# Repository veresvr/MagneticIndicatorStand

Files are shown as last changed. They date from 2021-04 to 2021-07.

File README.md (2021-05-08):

# Magnetic Indicator Stand

Designed for my small needs. You can make your own! All files are for SolidWorks 2020. Drawings are also available in .pdf

Assembly video is available on [YouTube](https://youtu.be/R4zijvSld24).  

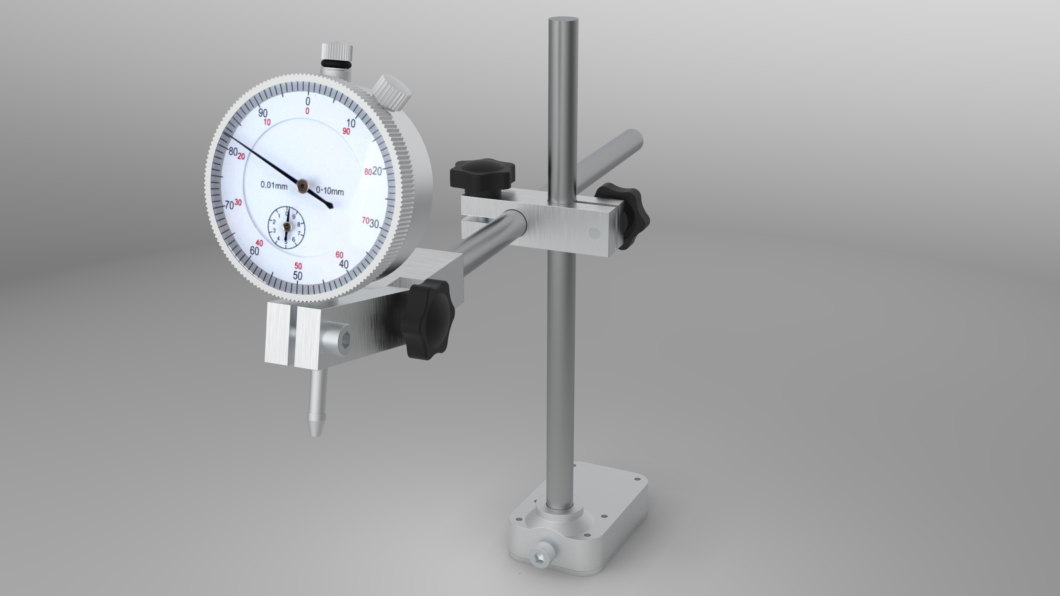
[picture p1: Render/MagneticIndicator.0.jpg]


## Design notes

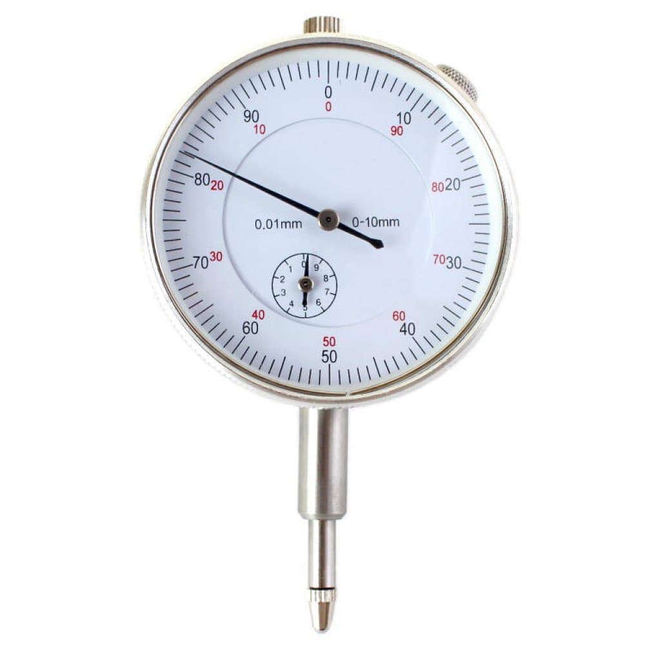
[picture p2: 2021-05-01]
Render/MagneticIndicator/photo_indicator.jpg

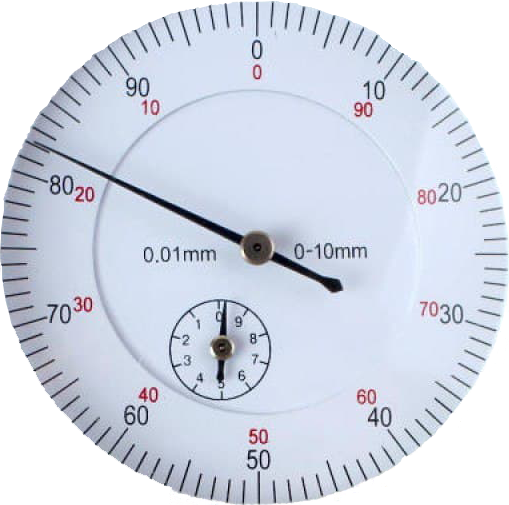
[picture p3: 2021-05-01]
Render/MagneticIndicator/photo_indicator.png

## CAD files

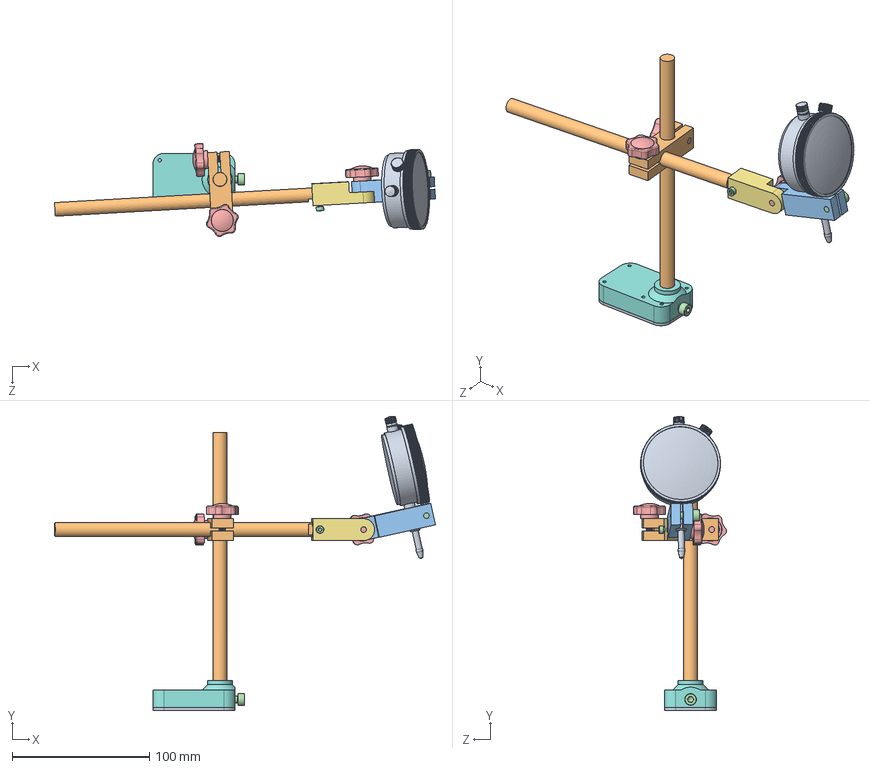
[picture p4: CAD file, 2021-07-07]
3D/MagneticIndicatorStand.SLDASM
277.9 x 214.5 x 68.0 mm
Dial Indicator
SteelRod x 2
IndicatorHolder
socket head cap screw_iso x 3
ClampingScrewKnob x 3
socket countersunk head screw_iso x 6
SecondPartOfIndicatorJoint
BasePart
Lid
MainJoint
Neodymium Magnet Square

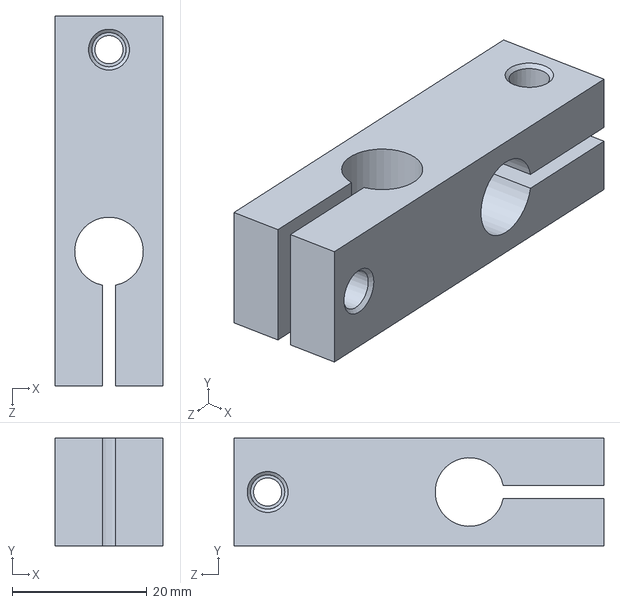
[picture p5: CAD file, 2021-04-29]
Render/AssemblyFiles/MainJoint.SLDPRT
16.0 x 16.0 x 55.0 mm

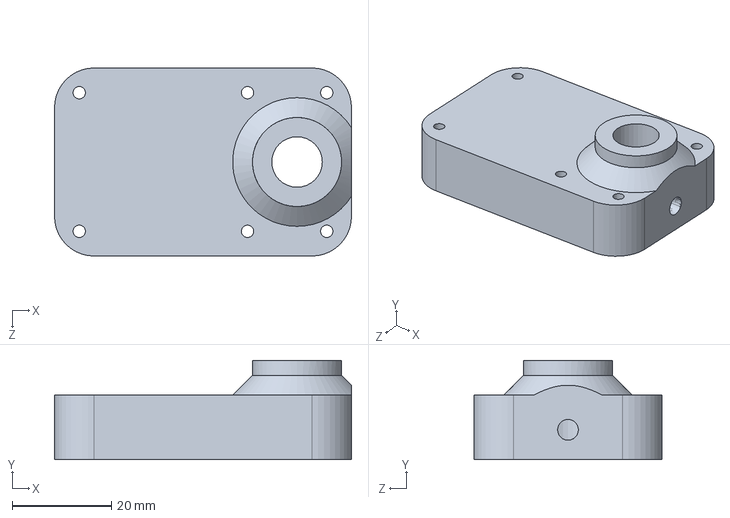
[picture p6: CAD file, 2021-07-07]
3D/BasePart.SLDPRT
60.0 x 20.0 x 38.0 mm

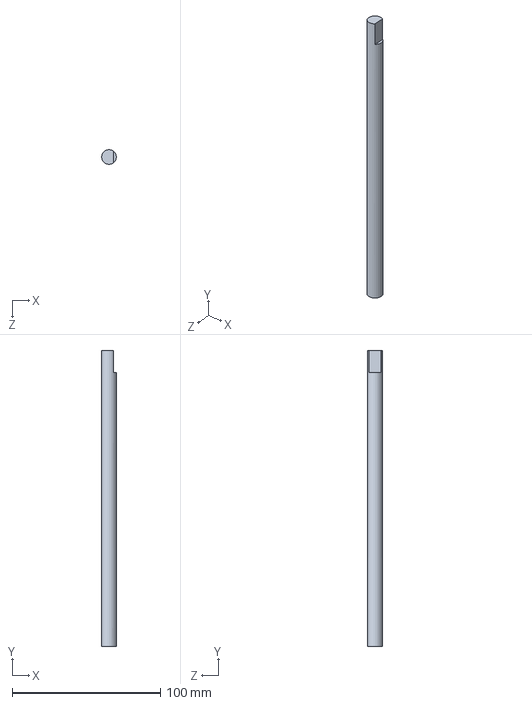
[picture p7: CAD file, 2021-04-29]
Render/AssemblyFiles/SteelRod.SLDPRT
10.0 x 200.0 x 10.0 mm

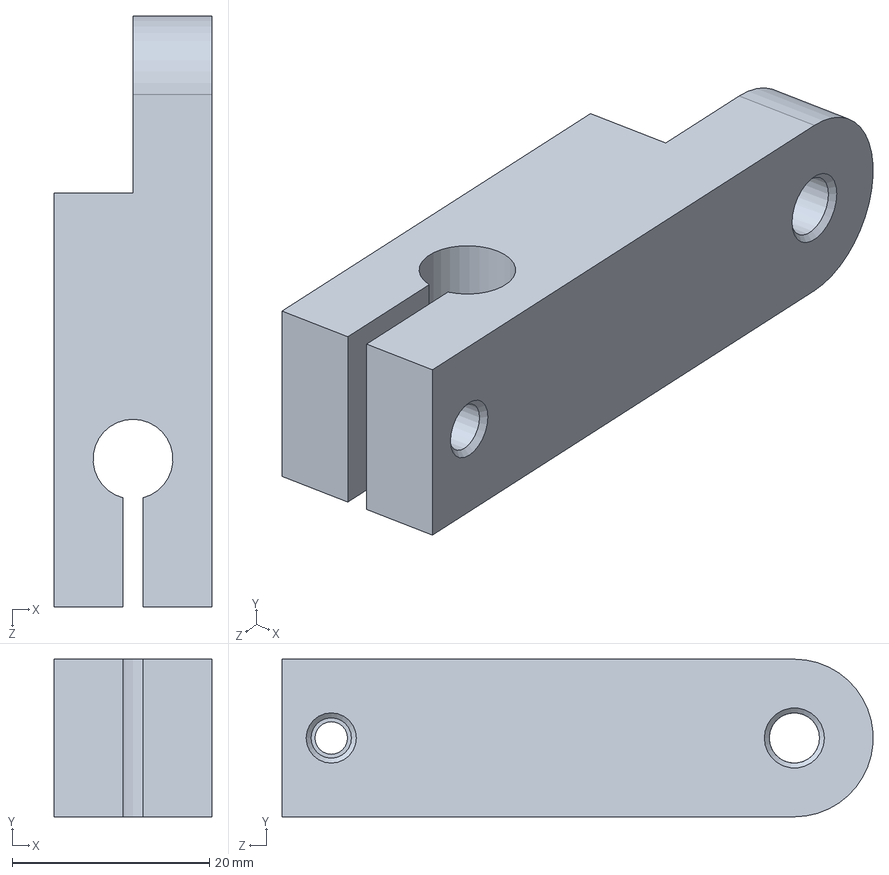
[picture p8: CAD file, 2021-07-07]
3D/IndicatorHolder.SLDPRT
16.0 x 16.0 x 60.0 mm

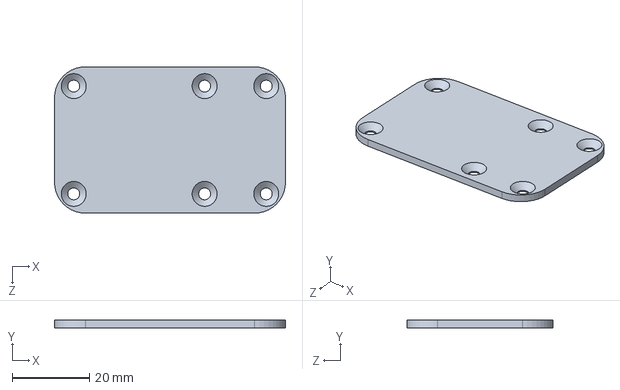
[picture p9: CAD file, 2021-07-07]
3D/Lid.SLDPRT
60.0 x 2.00 x 38.0 mm

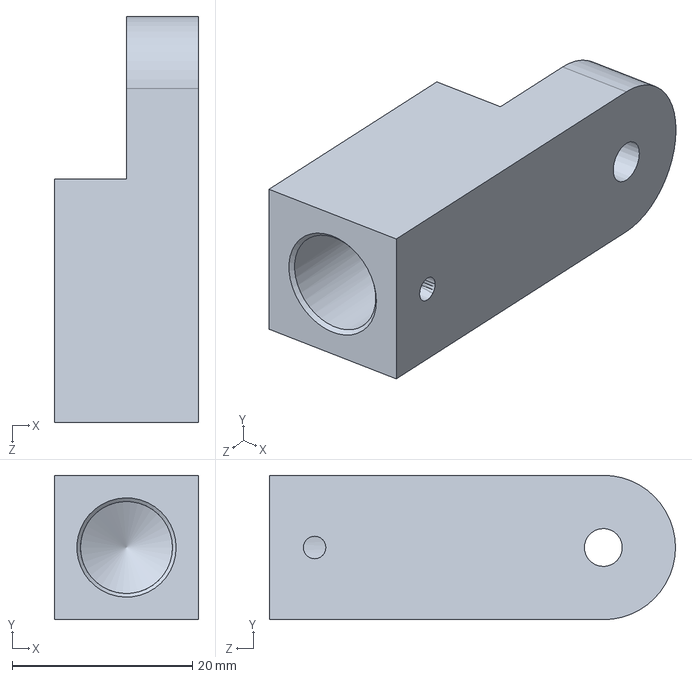
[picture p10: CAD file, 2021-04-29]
Render/AssemblyFiles/SecondPartOfIndicatorJoint.SLDPRT
16.0 x 16.0 x 45.0 mm

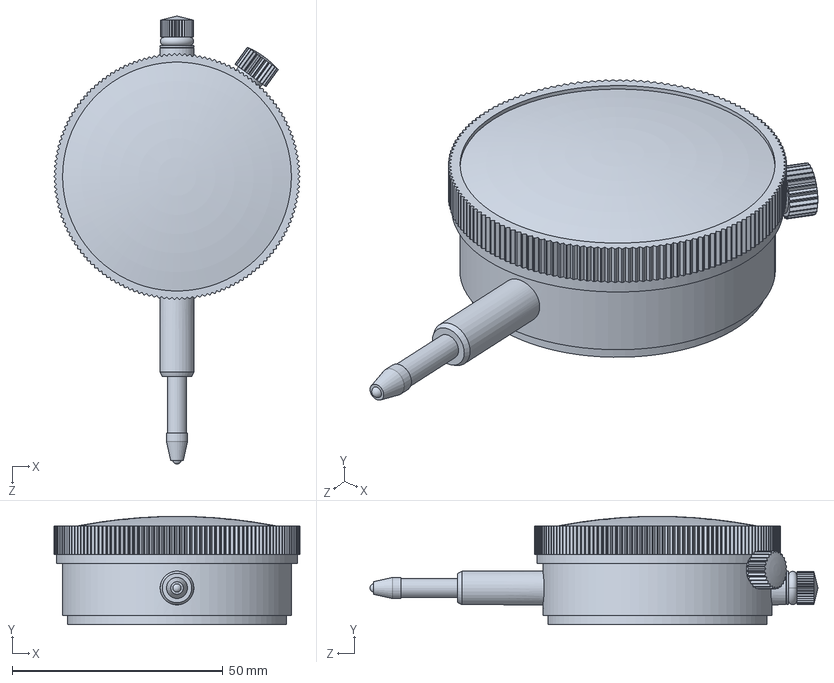
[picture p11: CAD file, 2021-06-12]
3D/Dial Indicator.SLDPRT
58.3 x 25.7 x 106.3 mm

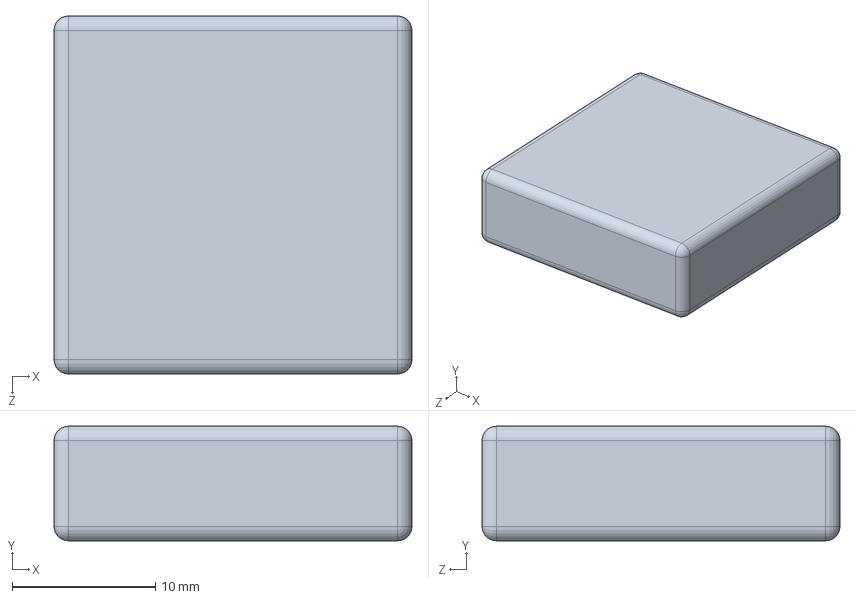
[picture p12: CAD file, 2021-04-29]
Render/AssemblyFiles/Neodymium Magnet Square.SLDPRT
25.0 x 8.00 x 25.0 mm

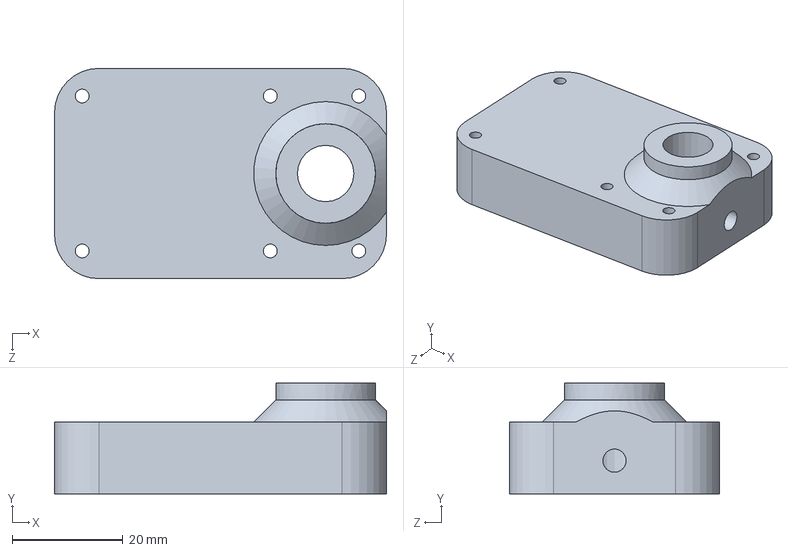
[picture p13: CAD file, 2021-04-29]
Render/AssemblyFiles/BasePart.SLDPRT
60.0 x 20.0 x 38.0 mm

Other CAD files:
3D/MainJoint.SLDPRT
Render/AssemblyFiles/MagneticIndicatorStand.SLDASM
3D/SecondPartOfIndicatorJoint.SLDPRT
Render/AssemblyFiles/IndicatorHolder.SLDPRT
3D/SteelRod.SLDPRT
3D/Neodymium Magnet Square.SLDPRT
Render/AssemblyFiles/Lid.SLDPRT
Render/AssemblyFiles/Dial Indicator.SLDPRT
3D/ClampingScrewKnob.SLDPRT
Drawings/BasePart.SLDDRW
Drawings/IndicatorHolder.SLDDRW
Drawings/Lid.SLDDRW
Drawings/MagneticIndicatorStand.SLDDRW
Drawings/MainJoint.SLDDRW
Drawings/SecondPartOfIndicatorJoint.SLDDRW
Drawings/SteelRod.SLDDRW
Render/AssemblyFiles/ClampingScrewKnob.SLDPRT
Render/AssemblyFiles/socket countersunk head screw_iso.sldprt
Render/AssemblyFiles/socket head cap screw_iso.sldprt

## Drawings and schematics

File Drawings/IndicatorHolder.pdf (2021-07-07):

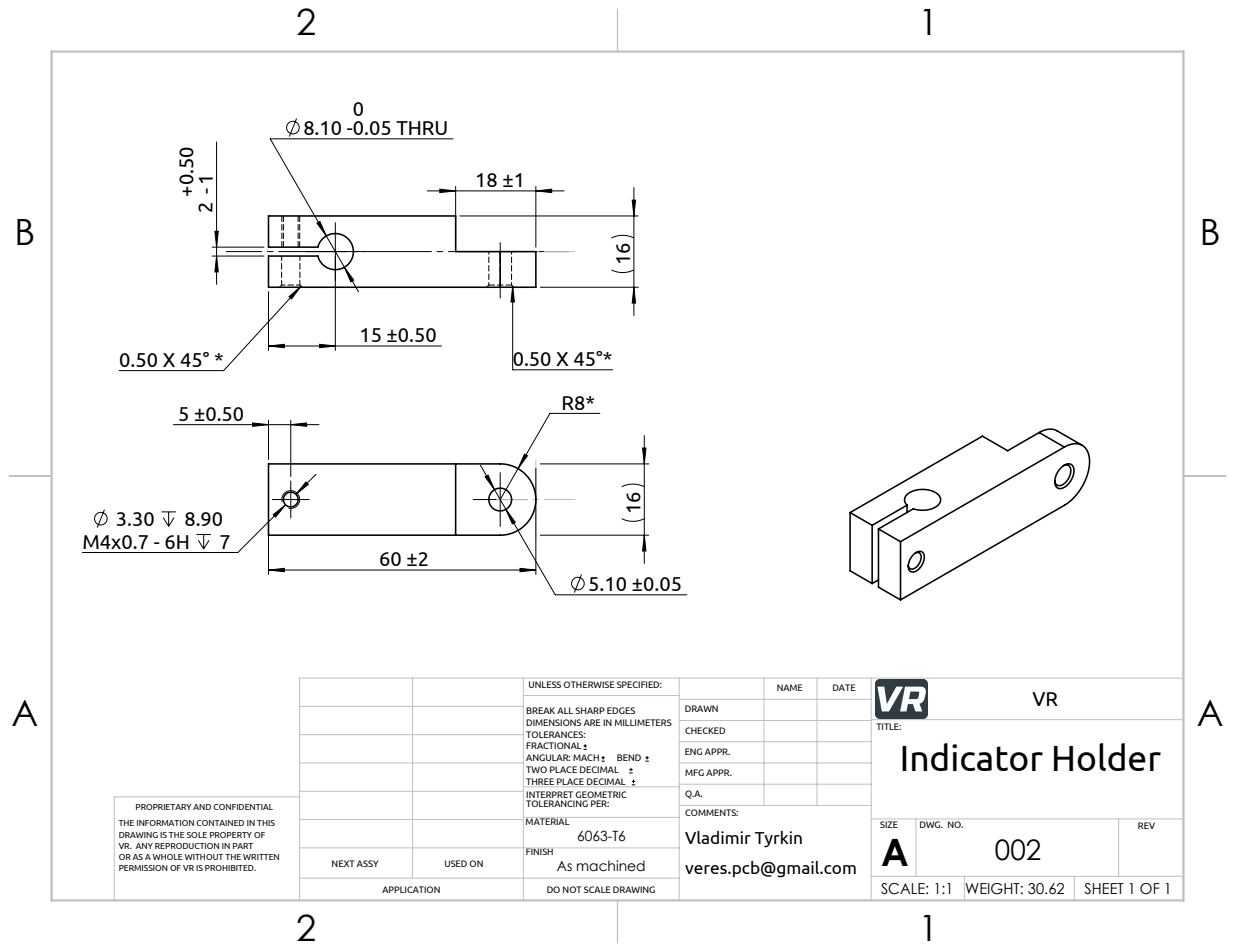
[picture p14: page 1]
0.05 THRU

UNLESS OTHERWISE SPECIFIED: | | DATE | VR NAME

BREAK ALL SHARP EDGES DIMENSIONS ARE IN MILLIMETERS TOLERANCES: FRACTIONAL ANGULAR: MACH BEND TWO PLACE DECIMAL THREE PLACE DECIMAL | DRAWN

CHECKED | | TITLE: Indicator Holder

ENG APPR.

MFG APPR.

INTERPRET GEOMETRIC TOLERANCING PER: | Q.A.
MATERIAL 6063-T6 | | SIZE A | DWG. NO. 002 | REV

PROPRIETARY AND CONFIDENTIAL
THE INFORMATION CONTAINED IN THIS
DRAWING IS THE SOLE PROPERTY OF
VR. ANY REPRODUCTION IN PART
OR AS A WHOLE WITHOUT THE WRITTEN
PERMISSION OF VR IS PROHIBITED.

COMMENTS:
Vladimir Tyrkin
veres.pcb@gmail.com

NEXT ASSY | USED ON | FINISH As machined

APPLICATION | DO NOT SCALE DRAWING | | SCALE: 1:1 | WEIGHT: 30.62 | SHEET 1 OF 1

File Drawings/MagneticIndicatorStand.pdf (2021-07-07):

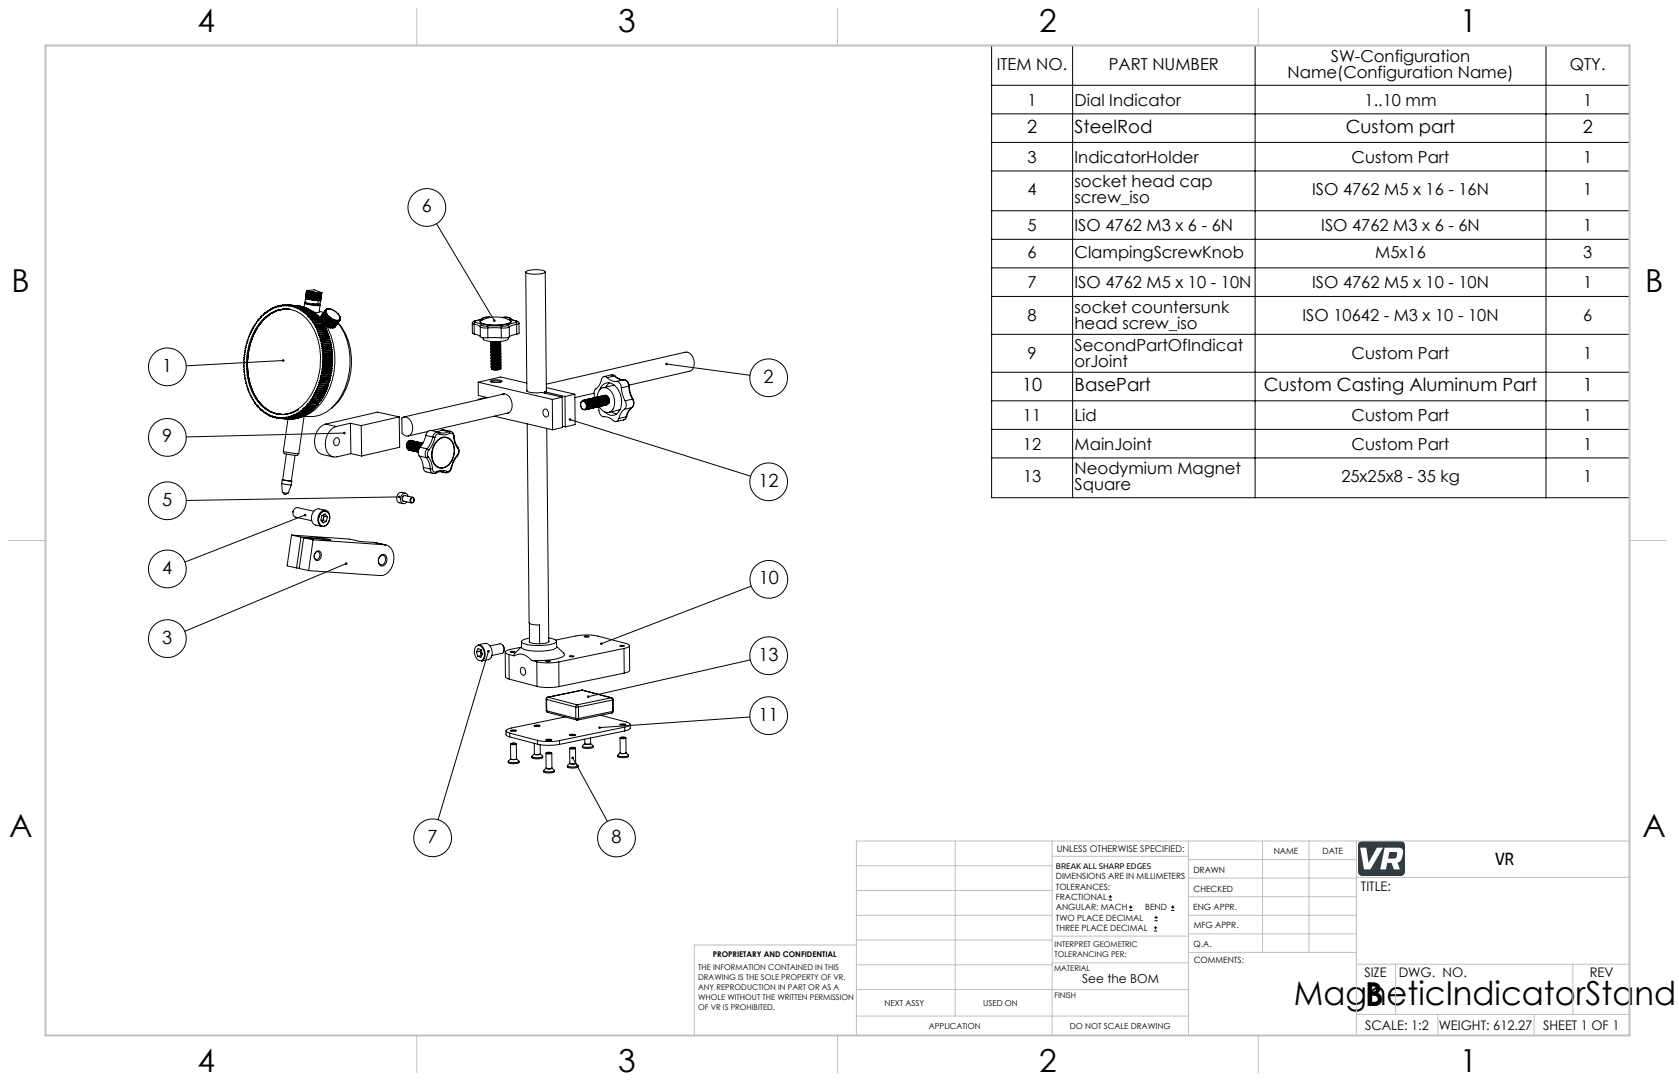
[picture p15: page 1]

ITEM NO. | PART NUMBER | SW-Configuration Name(Configuration Name) | QTY.

1 | Dial Indicator | 1..10 mm | 1
2 | SteelRod | Custom part | 2
3 | IndicatorHolder | Custom Part | 1
4 | socket head cap screw_iso | ISO 4762 M5 x 16 - 16N | 1

5 | ISO 4762 M3 x 6 - 6N | ISO 4762 M3 x 6 - 6N | 1
6 | ClampingScrewKnob | M5x16 | 3
7 | ISO 4762 M5 x 10 - 10N | ISO 4762 M5 x 10 - 10N | 1
8 | socket countersunk head screw_iso | ISO 10642 - M3 x 10 - 10N | 6
9 | SecondPartOfIndicat orJoint | Custom Part | 1
10 | BasePart | Custom Casting Aluminum Part | 1
11 | Lid | Custom Part | 1
12 | MainJoint | Custom Part | 1
13 | Neodymium Magnet Square | 25x25x8 - 35 kg | 1

UNLESS OTHERWISE SPECIFIED: | | NAME | DATE | VR
BREAK ALL SHARP EDGES DIMENSIONS ARE IN MILLIMETERS TOLERANCES: FRACTIONAL ANGULAR: MACH BEND TWO PLACE DECIMAL THREE PLACE DECIMAL | DRAWN

CHECKED | | | TITLE:

ENG APPR.
MFG APPR.

INTERPRET GEOMETRIC TOLERANCING PER: | Q.A.
MATERIAL See the BOM | | SIZE B | DWG. NO. | REV

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

NEXT ASSY | USED ON | FINISH

APPLICATION | DO NOT SCALE DRAWING | | SCALE: 1:2 | WEIGHT: 612.27 | SHEET 1 OF 1

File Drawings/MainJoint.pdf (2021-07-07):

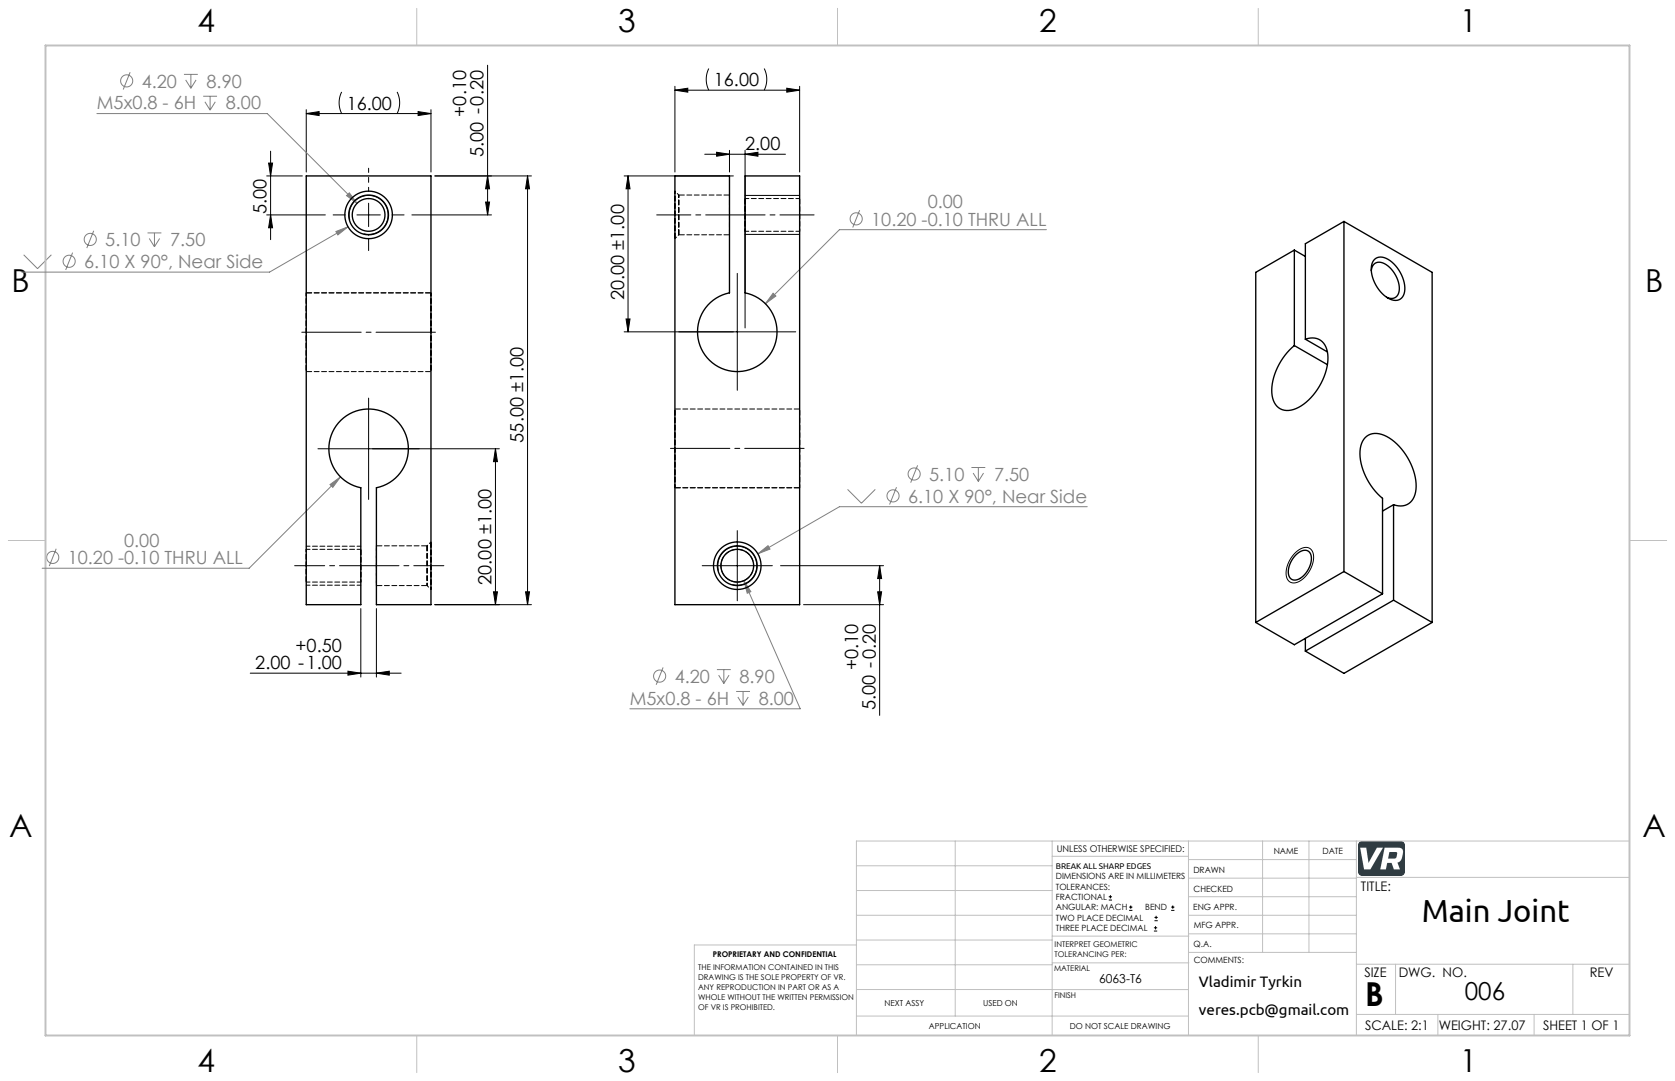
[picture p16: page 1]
10.20 - 0.10 THRU ALL; 5.10 7.50 6.10 X 90°, Near Side; OF VR IS PROHIBITED.; veres.pcb@gmail.com; Vladimir Tyrkin

UNLESS OTHERWISE SPECIFIED: | | NAME | DATE
BREAK ALL SHARP EDGES DIMENSIONS ARE IN MILLIMETERS TOLERANCES: FRACTIONAL ANGULAR: MACH BEND TWO PLACE DECIMAL THREE PLACE DECIMAL | DRAWN

CHECKED | | | TITLE: Main Joint

ENG APPR.
MFG APPR.

INTERPRET GEOMETRIC TOLERANCING PER: | Q.A.
MATERIAL 6063-T6 | | SIZE B | DWG. NO. 006 | REV

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

NEXT ASSY | USED ON | FINISH

APPLICATION | DO NOT SCALE DRAWING | | SCALE: 2:1 | WEIGHT: 27.07 | SHEET 1 OF 1

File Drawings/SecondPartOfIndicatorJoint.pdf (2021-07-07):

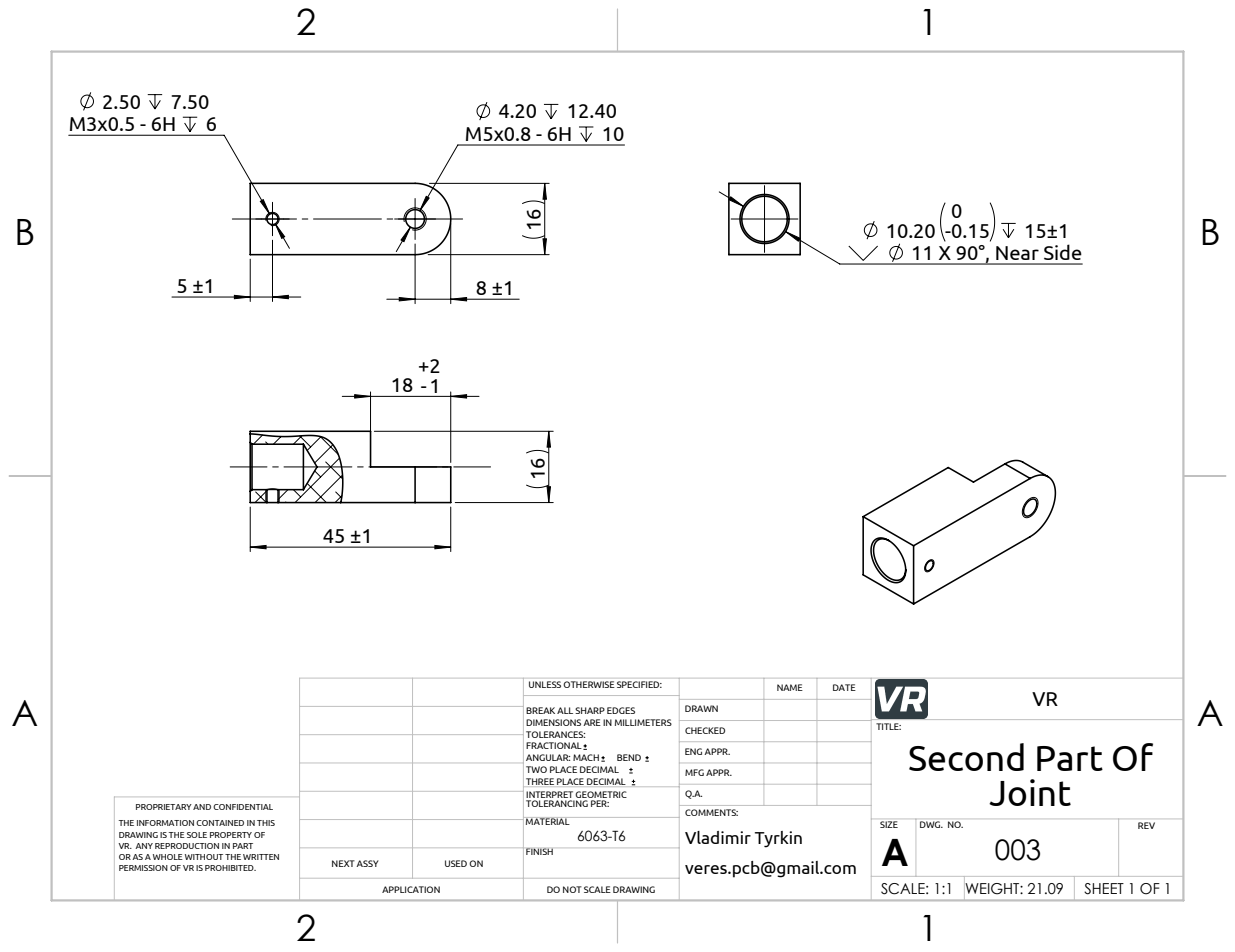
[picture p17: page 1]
10.20 - 11 X 90°, Near Side

UNLESS OTHERWISE SPECIFIED: | | DATE | VR NAME

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

CHECKED | | TITLE: Second Part Of Joint

ENG APPR.

MFG APPR.

INTERPRET GEOMETRIC TOLERANCING PER: | Q.A.
MATERIAL 6063-T6 | | SIZE A | DWG. NO. 003 | REV

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

COMMENTS:
Vladimir Tyrkin
veres.pcb@gmail.com

NEXT ASSY | USED ON | FINISH

APPLICATION | DO NOT SCALE DRAWING | | SCALE: 1:1 | WEIGHT: 21.09 | SHEET 1 OF 1

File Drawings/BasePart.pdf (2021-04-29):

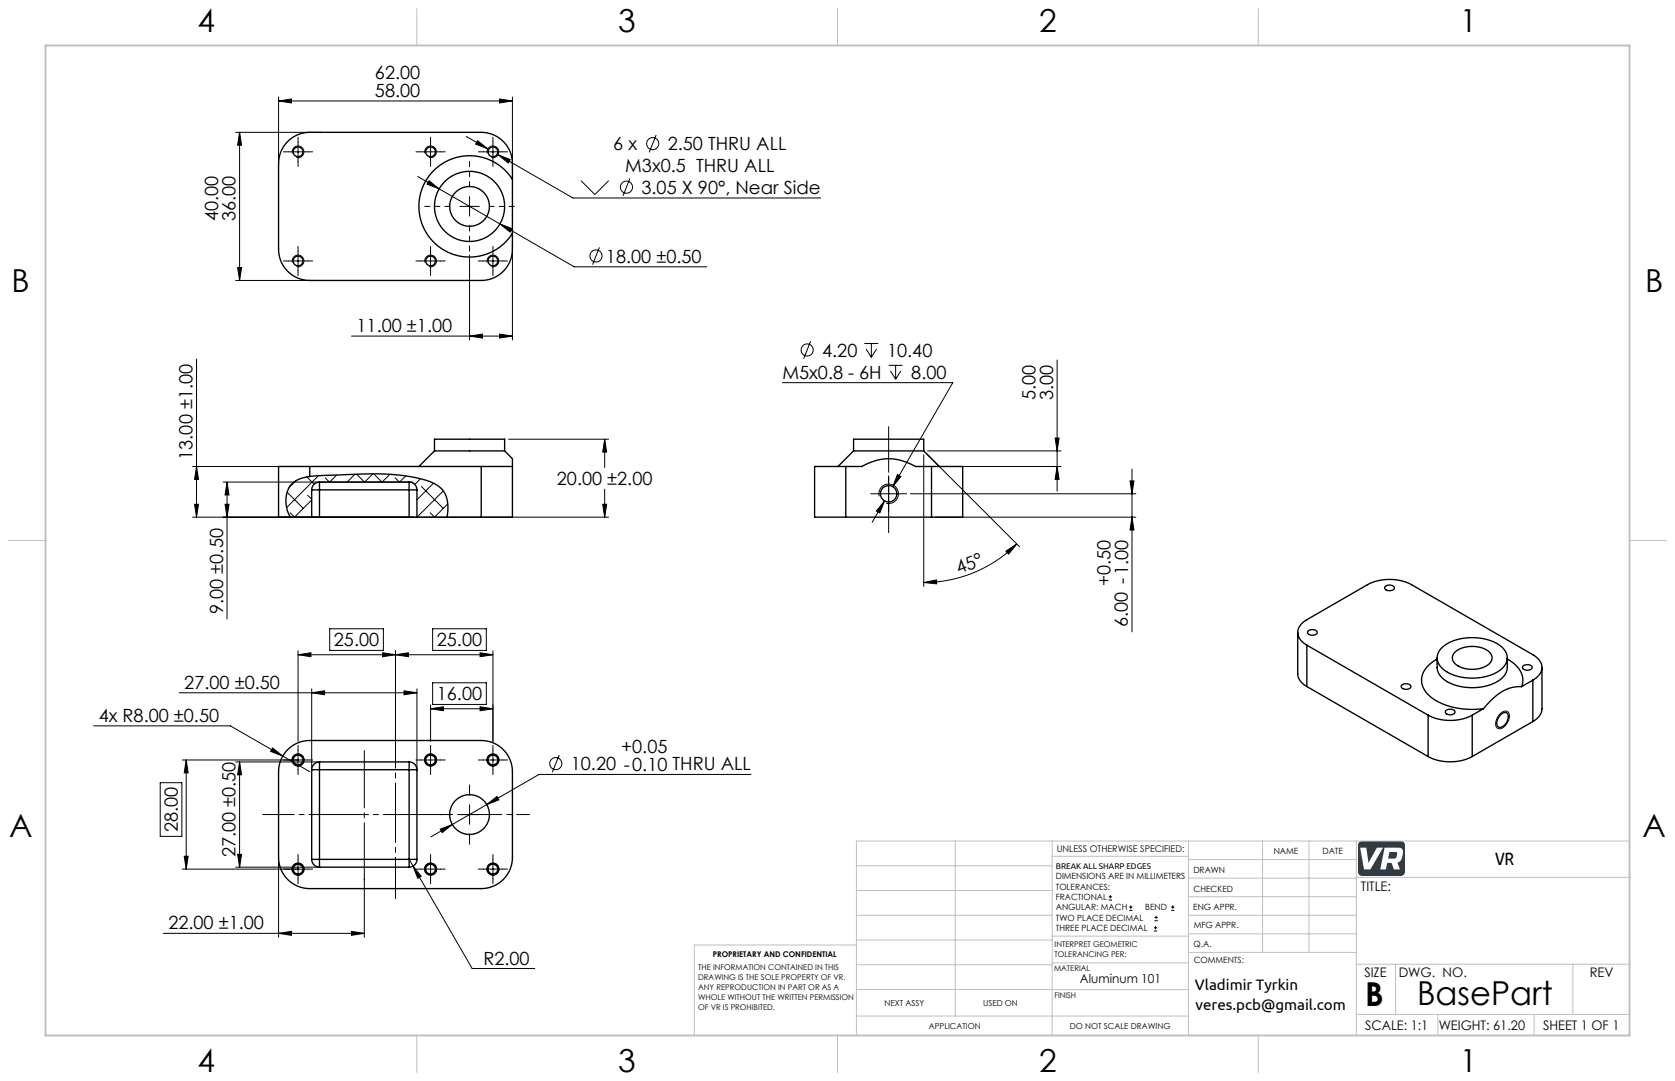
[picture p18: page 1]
2.50 THRU ALL; M3x0.5 THRU ALL 3.05 X 90°, Near Side; 0.10 THRU ALL

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

CHECKED | | | TITLE:

ENG APPR.
MFG APPR.

INTERPRET GEOMETRIC TOLERANCING PER: | Q.A.
MATERIAL Aluminum 101 | | SIZE B | DWG. NO. BasePart | REV

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

COMMENTS:
Vladimir Tyrkin
veres.pcb@gmail.com

NEXT ASSY | USED ON | FINISH

APPLICATION | DO NOT SCALE DRAWING | | SCALE: 1:1 | WEIGHT: 61.20 | SHEET 1 OF 1

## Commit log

2021-03-14 Added indicator, rods and fasteners
    [ClampingScrewKnob.SLDPRT, Dial Indicator.SLDPRT, MagneticIndicatorStand.SLDASM]
2021-03-14 Updated joint
    [ClampingScrewKnob.SLDPRT, Dial Indicator.SLDPRT, MagneticIndicatorStand.SLDASM]
2021-03-14 Added middle joint
    [Base.SLDPRT, MagneticIndicatorStand.SLDASM]
2021-03-15 Updated some part dimensions
    [Base.SLDPRT, BasePart.SLDPRT, MagneticIndicatorStand.SLDASM]
2021-03-16 Added some drawings
    [MagneticIndicatorStand.SLDASM, Part4.SLDDRW, Part4.SLDPRT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]
2021-03-18 Maked parts non virtuality and add some drawings
    [MagneticIndicatorStand.SLDASM, Part1.SLDDRW, Part1.SLDPRT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]
2021-03-20 Updated Part3 drawing, updated Base part and add its drawing
    [BasePart.SLDDRW, BasePart.SLDPRT, MagneticIndicatorStand.SLDASM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]
2021-03-20 Replaced one part. Added drawing
    [BasePart.SLDDRW, BasePart.SLDPRT, MagneticIndicatorStand.SLDASM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]
2021-03-21 Added lid and its drawing. Added one more part. Added BOM
    [BasePart.SLDPRT, ClampingScrewKnob.SLDPRT, Dial Indicator.SLDPRT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]
2021-04-06 Replaced some parts, updated its drawings and generated pdf files
    [BasePart.SLDDRW, Lid.SLDDRW, Lid.SLDPRT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]
2021-04-06 Drawings for all parts has done
    [BasePart.SLDDRW, BasePart.SLDPRT, ClampingScrewKnob.SLDPRT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]
2021-04-17 Replaced screw knob and add mass parameters
    [ClampingScrewKnob.SLDPRT, ClampingScrewKnobFromAliexpress.SLDPRT, Dial Indicator.SLDPRT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]
2021-04-17 Added a magnet
    [BasePart.SLDPRT, MagneticIndicatorStand.SLDASM, Neodymium Magnet.SLDPRT]
2021-04-22 Relocated the parts
    [BasePart.SLDPRT, ClampingScrewKnobFromAliexpress.SLDPRT, Dial Indicator.SLDPRT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]
2021-04-28 Updated the assembly and parts because of new neodymium magnet
    [BasePart.SLDPRT, Lid.SLDPRT, MagneticIndicatorStand.SLDASM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]
2021-04-29 Fixed some issues in the parts, made drawings for it
    [BasePart.SLDDRW, BasePart.SLDPRT, ClampingScrewKnob.SLDPRT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]
2021-04-29 Renamed some parts and prepared for rendering
    [BasePart.SLDPRT, ClampingScrewKnob.SLDPRT, Dial Indicator.SLDPRT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]
2021-04-29 Imported the assembly to new Unreal project
2021-04-29 Added some materials
2021-05-01 Changed the render to Keyshot 9. Added basic materials and set up the scene
2021-05-08 Renamed one part and drawing. Updated the readme file. Has changed the size of rendered image
    [IndicatorHolder.SLDDRW, Part1.SLDDRW, SecondPartOfIndicatorJoint.SLDDRW]
2021-05-29 Added the main assembly exploded view drawing
    [BasePart.SLDPRT, MagneticIndicatorStand.SLDASM, MagneticIndicatorStand.SLDDRW]
2021-06-06 Almost done the movie sequence
    [Lid.SLDPRT, MagneticIndicatorStand.SLDASM]
2021-06-12 Updated properties in the parts, updated the BOM. Added internet links to some positions in the BOM
    [BasePart.SLDPRT, ClampingScrewKnob.SLDPRT, Dial Indicator.SLDPRT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]
2021-07-07 Updated all parts drawings and the pdf documents.
    [BasePart.SLDPRT, IndicatorHolder.SLDDRW, IndicatorHolder.SLDPRT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]
